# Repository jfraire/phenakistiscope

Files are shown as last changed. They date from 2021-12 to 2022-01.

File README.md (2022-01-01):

# phenakistiscope
An ATtiny85 circuit to build a phénakistiscope

A phénakistiscope is a toy invented in the XIX century, and it is one of the first devices to display animations.

It is usually a disk with the animation frames painted in one face, at regular intervals. It has cut-outs, also spaced regularly. The user would see the disk reflected on a mirror, through the slits. When the disk is spun, the animation comes to life!

It is easy to find beautiful disks from that time. You can find a few in the [Wikipedia page](https://en.wikipedia.org/wiki/Phenakistiscope). If you are interested, be sure to take a look at [The wheel of life](http://www.stephenherbert.co.uk/wheelHOME.htm). It is a site full of historic information and it contains some of the most beautiful disks I've seen.

## This project

Another way of animating these disks is with a physical device. In these times, a small, rotating servo-motor and some LEDs that turn on and off will work. To synchronize the the motor with the LEDs, this project uses a couple of potentiometers. This is nice: You end up playing with the knobs to get your animation just right.

In this repository you will find the electronic schema, the code, the BOM, and the KiCAD file.

Also, note that the terms *zoetrope* and *phénakistiscope* refer to two different devices. However, zoetropes may include the same kind of disks at the bottom of the animation drums and they exploit the same principle to display animations. The KiCAD files are named *zoetrope*.

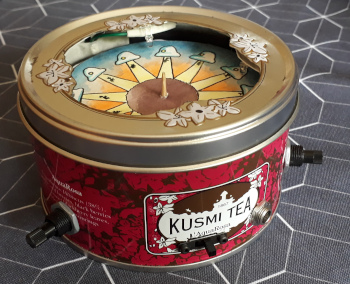
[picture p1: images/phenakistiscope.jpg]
The assembled phénakistiscope


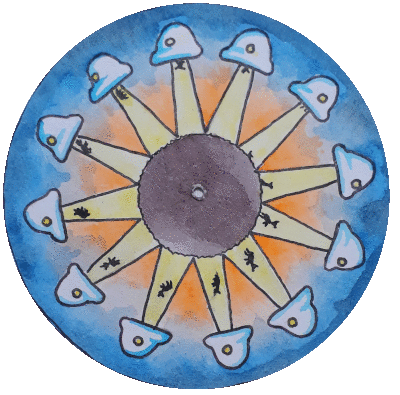
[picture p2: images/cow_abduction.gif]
A sample animated disk


## Bill of materials

Item | Reference | Description
---|---|---
U1|LM7805|5V voltage regulator
U2|ATTINY85-20PU|ATtiny85 micro-controller
R1|220 Ω|Resistor
C1|0.33 μF|Capacitor
C2|0.1 μF|Capacitor
C3|0.1 μF|Capacitor
J1|Screw Terminal 01x02|Terminal block for power 
J2|Conn 01x03 Male|3 pins, male connector for the servo motor
J3|Screw Terminal 01x06|Terminal block for the potentiometers
J4|Screw Terminal 01x02|Terminal block for the LEDs

And not in the schema:

1. Continuous rotation servo motor FS90R
2. Two 10kΩ potentiometers
3. Four white LEDs

## Contents of the repository

You will find the KiCAD files under `kicad`. The code and make file for the micro-controller is in `src`. The KiCAD files include the lay out of the PCB, which is small and easy to solder. The `img` folder contains an example disk.

## Credits

The makefile to compile this project was taken from the book [Make: AVR Programming](https://www.amazon.fr/Make-AVR-Programming-Elliot-Williams/dp/1449355781), by Elliot Williams. This book has given me more than a few hours of pleasure.

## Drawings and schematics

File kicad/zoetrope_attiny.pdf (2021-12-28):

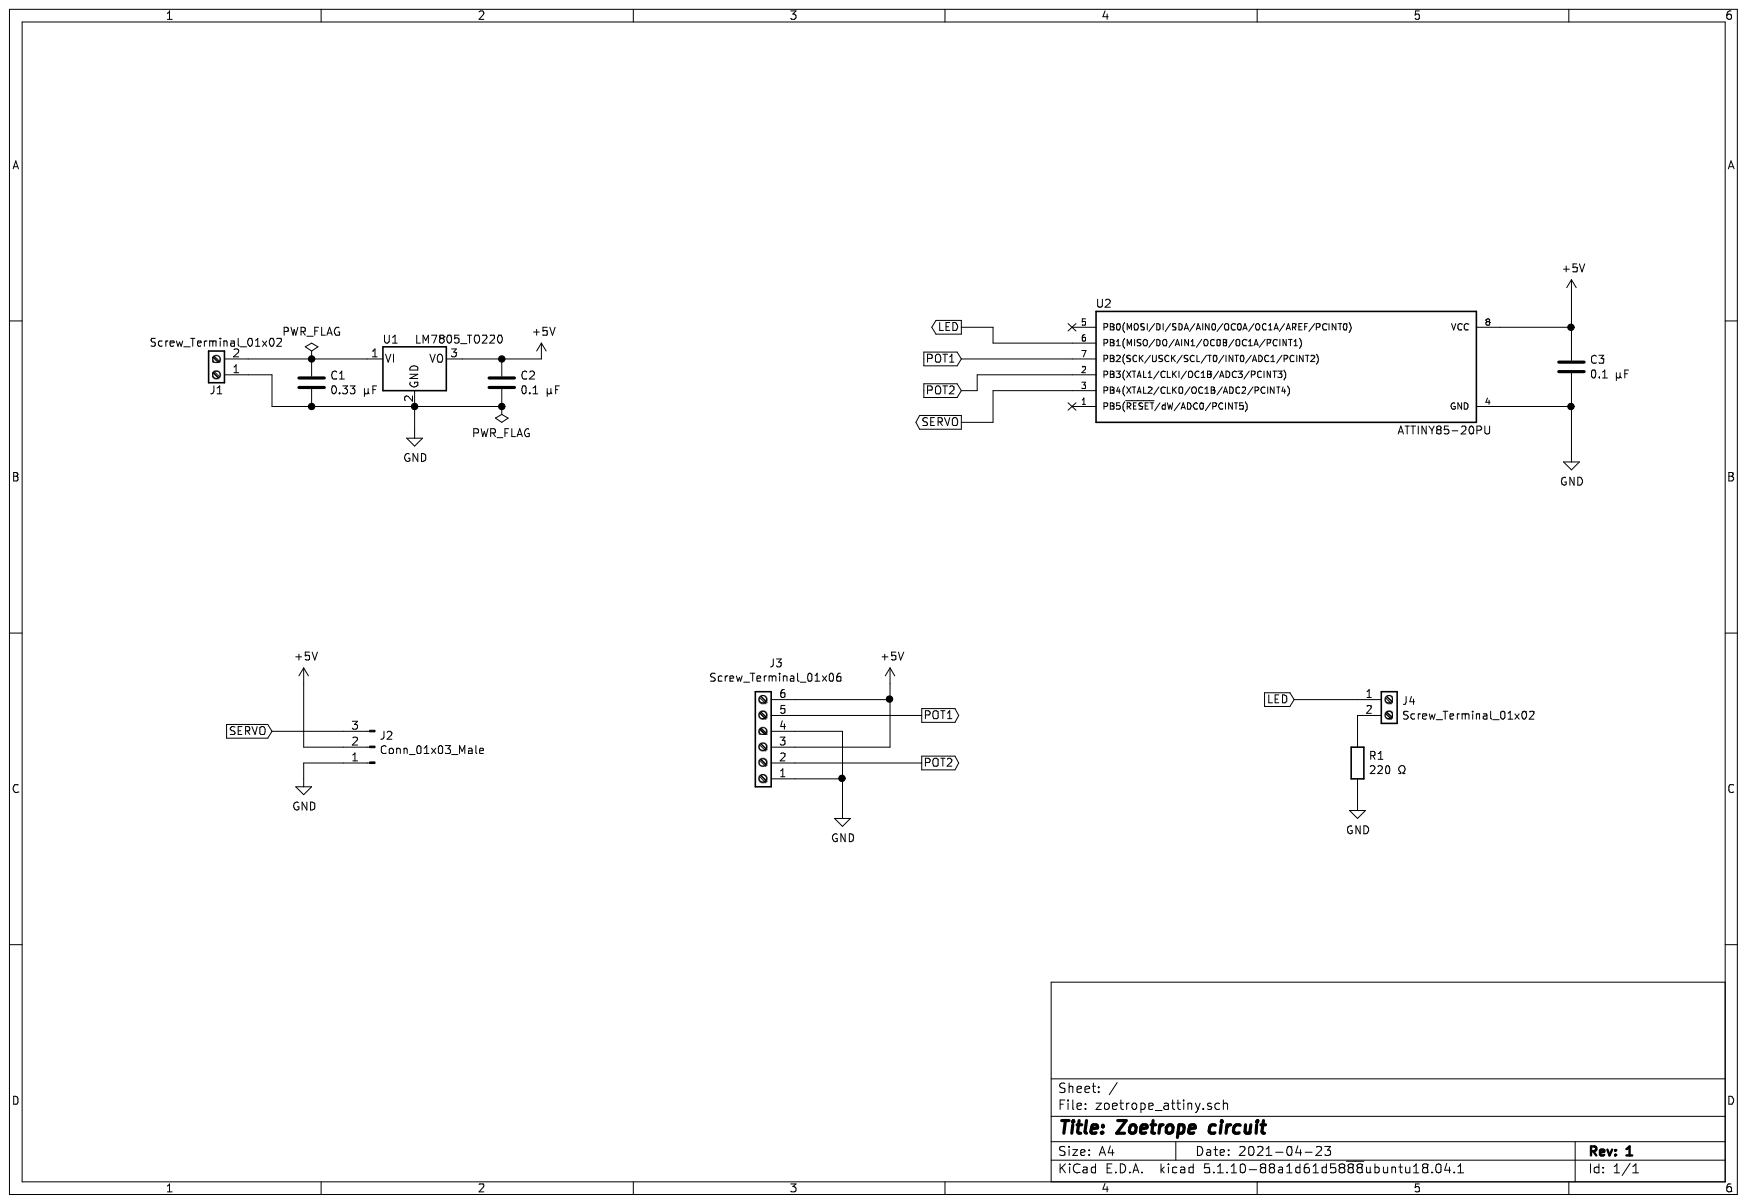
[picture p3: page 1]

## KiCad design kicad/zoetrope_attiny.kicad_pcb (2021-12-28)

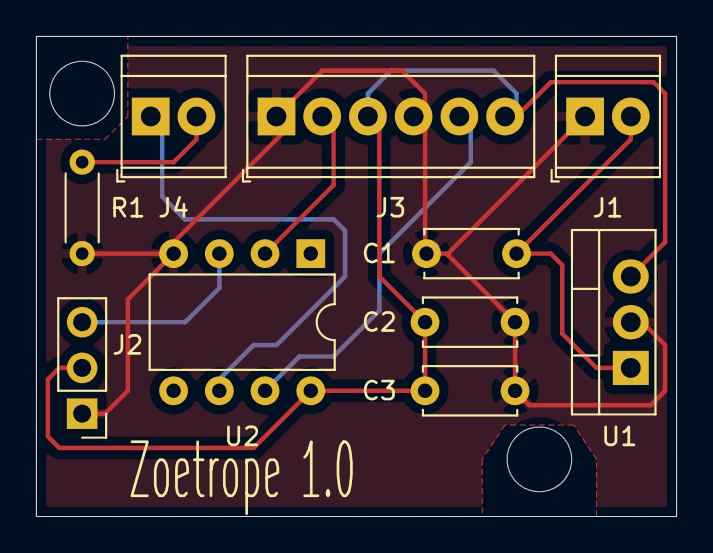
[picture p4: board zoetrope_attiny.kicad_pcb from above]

Board: 2 copper layers, 35.6 x 26.7 mm, 10 parts (0 on the bottom side), 8 nets.

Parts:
C1: 0.33 μF; C_Disc_D5.0mm_W2.5mm_P5.00mm
C2, C3: 0.1 μF; C_Disc_D5.0mm_W2.5mm_P5.00mm
J1, J4: Screw_Terminal_01x02; TerminalBlock_TE_282834-2_1x02_P2.54mm_Horizontal
J2: Conn_01x03_Male; PinHeader_1x03_P2.54mm_Vertical
J3: Screw_Terminal_01x06; TerminalBlock_TE_282834-6_1x06_P2.54mm_Horizontal
R1: 220 Ω; R_Axial_DIN0204_L3.6mm_D1.6mm_P5.08mm_Horizontal
U1: LM7805_TO220; TO-220-3_Vertical
U2: ATTINY85-20PU; DIP-8_W7.62mm

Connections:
+5V: C2.1, C3.1, J2.2, J3.3, J3.6, U1.3, U2.8
GND: C1.2, C2.2, C3.2, J1.1, J2.1, J3.1, J3.4, R1.2, U1.2, U2.4
LED: J4.1, U2.6
unnamed: C1.1, J1.2, U1.1
unnamed: J4.2, R1.1
POT1: J3.5, U2.7
POT2: J3.2, U2.2
SERVO: J2.3, U2.3

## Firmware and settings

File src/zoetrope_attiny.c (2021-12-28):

/* -----------------------------------------------
   Program that controls the period of a PWM
   signal with a potentiometer, while it moves a
   servo motor at a constant speed.
   It uses timer 0, 1, and the ADC
   Works with ATTiny85
   ----------------------------------------------- */
#include <avr/io.h>
#include <avr/interrupt.h>
#include <util/delay.h>

#define LED PB1
#define SERVO PB4
#define POT1 ADC1
#define POT2 ADC3

const uint8_t bright_time = 3;

uint8_t read_adc(uint8_t channel) {
    ADMUX &= (0xF0);                        // Clear the channel selection
    ADMUX |= channel;                       // Read from ADCX
    ADCSRA |= (1 << ADSC);                  // Start conversion
    loop_until_bit_is_clear(ADCSRA, ADSC);
    return ADCH;
}

int main(void) {
    // Set LED and SERVO pins for output
    DDRB = (1 << SERVO) | (1 << LED);

    // Initialize the ADC -- Use VCC as reference
    ADMUX = 0;                              // Clearing REFS0-2 selects VCC as ref
    ADMUX  |= (1 << ADLAR);                 // Use only the most significant 8 bits
    ADCSRA |= (1 << ADPS1) | (1 << ADPS0);  // Set prescaler to 1/8 
    ADCSRA |= (1 << ADEN);                  // Enable ADC

    // Configure timer 0 in fast PWM mode with variable period
    // The period is modified by chaning OCR0A, and the signal turns off on OCR0B
    // So, output is at OC0B, PB1
    TCCR0A = (1 << WGM01) | (1 << WGM00);   // Fast PWM mode reseting at OCR0A
    TCCR0B = (1 << WGM02);                  // (mode 7)
    TCCR0A |= (1 << COM0B1);                // Output non-inverting on OC0B (PB1)
    TCCR0B |= (1 << CS02) | (1 << CS00);    // Set the prescaler to 1/1024
    OCR0B = bright_time;                    // Time to keep the output high

    // Configure timer 1 in PWM mode. Output is PB4 (OC1B) --> SERVO
    // The ON period should last between 900 and 2100 us --> 1200 us
    // And the frequency of the signal should be between 50 and 100 Hz
    // Because it is an 8-bit timer, its period is divided by 256, maximum
    // A prescaler of 64 will give a period of 16.4 ms with a resolution of 64 us
    // The 1200 us can be divided into only 18.75 bins...
    GTCCR = (1 << PWM1B);                    // Enable PWM mode on OCR1A
    GTCCR |= (1 << COM1B1);                  // OC1A turns on at 0, resets at OCR1C
    TCCR1 = (1 << CS12) | (1 << CS11) | (1 << CS10);
    OCR1C = 0xFF;                           // Pulse duration of 256 * 64 us, or 16.38 ms

    // ------ Event loop ------ //
    while (1) {
        // Read the 1st potentiometer and change the period of the PWM
        // signal for the LED in timer 0
        OCR0A = read_adc(1);

        // Read the 2nd potentiometer and change the high duration of the PWM
        // signal for the servo motor in timer 1
        // The 0-255 signal should be mapped to 0-18.75
        // The minimum pulse is 900 us, or 14 clock ticks of 64 us
        uint8_t speed_servo = read_adc(3);
        OCR1B = (uint8_t)(18.75 * speed_servo / 255.0 + 14.06);
    }
    return 0;
}
